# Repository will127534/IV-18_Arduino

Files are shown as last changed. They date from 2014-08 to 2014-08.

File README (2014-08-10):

This program is to control MAX6921 for IV-18 VFD display 
To control the MAX6921 needs three pin,CLK,LOAD DATA,just like the shift regester
But the difference is MAX6921 is just using 19bit with LSB first.

Another thing is how you connect MAX6921 to the IV-18 tube.
the connection begin from the third one,with a,b,c,e,d,f,g,h,i
then comes with 1~9 digit.
the digit is already inverted(since LSB first)

The program also pack the DS1307 control (http://bildr.org/2011/03/ds1307-arduino/) to provide RTC .  

To enter the current time,just using the COM port and enter S, and you can enter the current time.

Here is the BLOG:(chinese)
http://will-123456.blogspot.tw/2014/01/iv-18-arduino-shield.html

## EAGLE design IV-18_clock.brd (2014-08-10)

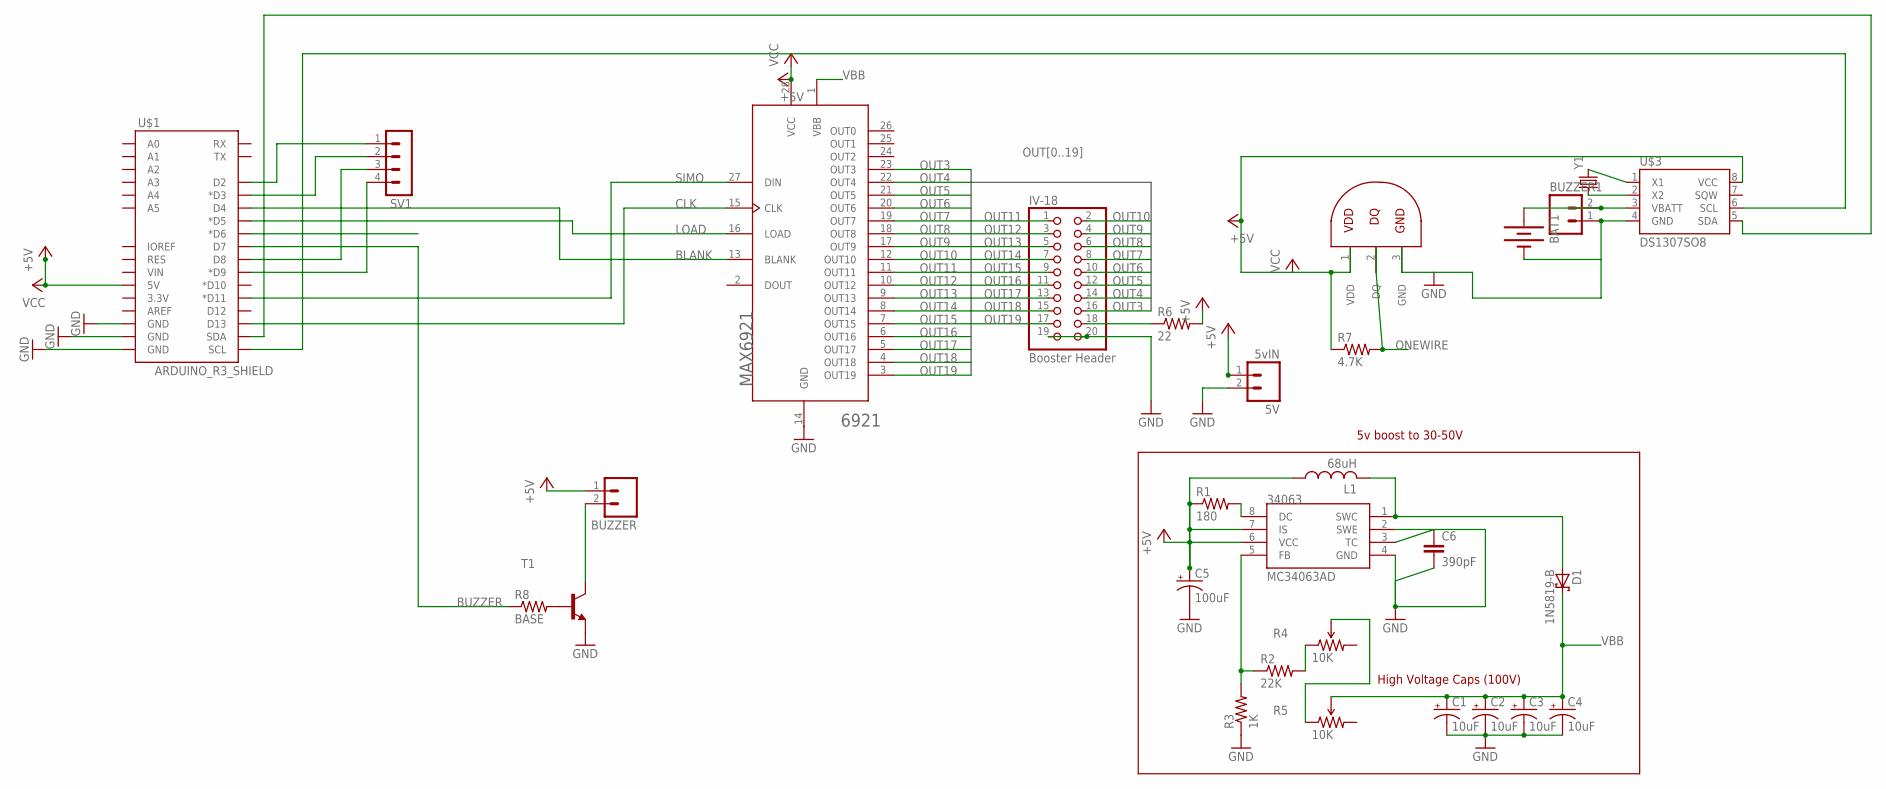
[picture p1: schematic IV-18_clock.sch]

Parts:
5V: 5vIN; 1X02
6921: MAX6921_AFSOIC(W); SO28L
34063: MC34063AD; SOIC8
BAT1: BATTERY20PTH; BATTCOM_20MM_PTH
BUZZER, BUZZER1: 1X02
C1, C2, C3, C4: 10uF; E2,5-6
C5: 100uF; E2,5-6
C6: 390pF; CAP-PTH-5MM
D1: 1N5819-B; DO41-7.6
DS18B20: DS18B20; TO92-CBE@1
IV-18: Booster Header; 2X10
L1: 68uH; 6000-XXXX-RC
R1: 180; 0204/7
R2: 22K; 0204/7
R3: 1K; 0204/7
R4, R5: 10K; TRIM_POT_PTH
R6: 22; 0204/7
R7: 4.7K; 0204/7
R8: BASE; 0204/7
SV1: MA04-1
T1: TO92-EBC
U$1: ARDUINO_R3_SHIELD; UNO_R3_SHIELD
U$3: DS1307SO8; SO08
Y1: CRYSTALTC26H_EZ; TC26HEZ

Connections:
+5V: 5V.1, 6921.28 (VCC), 34063.6 (VCC), 34063.7 (IS), BUZZER.1, C5.+, DS18B20.1 (VDD), L1.1, R1.1, R6.2, R7.1, U$1.5V, U$3.8 (VCC)
BLANK: 6921.13 (BLANK), U$1.D4
BUZZER: R8.1, U$1.D7
CLK: 6921.15 (CLK), U$1.D13
GND: 5V.2, 6921.14 (GND), 34063.2 (SWE), 34063.4 (GND), BAT1.2 (-), BUZZER1.1, C1.-, C2.-, C3.-, C4.-, C5.-, C6.2, DS18B20.3 (GND), IV-18.19, IV-18.20, R3.1, T1.E, U$1.GND@0 (GND), U$1.GND@1 (GND), U$1.GND@2 (GND), U$3.4 (GND)
LOAD: 6921.16 (LOAD), U$1.D5 (*D5)
unnamed: IV-18.18, R6.1
unnamed: R2.2, R4.1 (CCW)
unnamed: 34063.1 (SWC), D1.A, L1.2
unnamed: R4.2 (WIPER), R5.1 (CCW)
unnamed: 34063.8 (DC), R1.2
unnamed: 34063.3 (TC), C6.1
unnamed: 34063.5 (FB), R2.1, R3.2
unnamed: R8.2, T1.B
unnamed: SV1.1, U$1.D2
unnamed: SV1.2, U$1.D3 (*D3)
unnamed: SV1.3, U$1.D8
unnamed: BUZZER.2, T1.C
unnamed: U$3.1 (X1), Y1.2
unnamed: U$3.2 (X2), Y1.1
unnamed: U$1.SCL, U$3.6 (SCL)
unnamed: BAT1.1 (+), BUZZER1.2, U$3.3 (VBATT)
unnamed: U$1.SDA, U$3.5 (SDA)
unnamed: SV1.4, U$1.D9 (*D9)
ONEWIRE: DS18B20.2 (DQ), R7.2, U$1.D6 (*D6)
OUT3: 6921.23 (OUT3), IV-18.16
OUT4: 6921.22 (OUT4), IV-18.14
OUT5: 6921.21 (OUT5), IV-18.12
OUT6: 6921.20 (OUT6), IV-18.10
OUT7: 6921.19 (OUT7), IV-18.8
OUT8: 6921.18 (OUT8), IV-18.6
OUT9: 6921.17 (OUT9), IV-18.4
OUT10: 6921.12 (OUT10), IV-18.2
OUT11: 6921.11 (OUT11), IV-18.1
OUT12: 6921.10 (OUT12), IV-18.3
OUT13: 6921.9 (OUT13), IV-18.5
OUT14: 6921.8 (OUT14), IV-18.7
OUT15: 6921.7 (OUT15), IV-18.9
OUT16: 6921.6 (OUT16), IV-18.11
OUT17: 6921.5 (OUT17), IV-18.13
OUT18: 6921.4 (OUT18), IV-18.15
OUT19: 6921.3 (OUT19), IV-18.17
SIMO: 6921.27 (DIN), U$1.D11 (*D11)
VBB: 6921.1 (VBB), C1.+, C2.+, C3.+, C4.+, D1.C, R5.2 (WIPER)

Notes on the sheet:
5v boost to 30-50V
High Voltage Caps (100V)

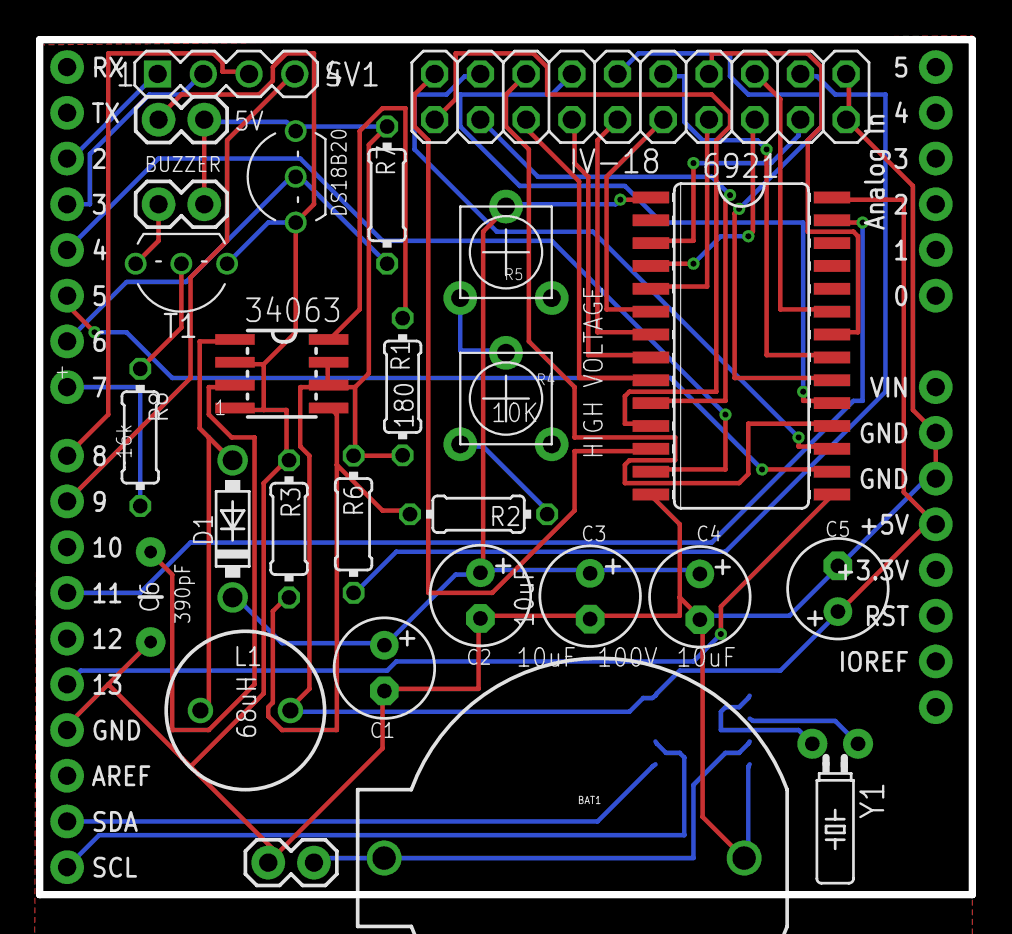
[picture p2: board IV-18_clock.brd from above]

Board: 2 copper layers, 51.8 x 47.5 mm, 29 parts (1 on the bottom side), 44 nets.

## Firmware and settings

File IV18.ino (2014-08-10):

#include <Arduino.h>

#include <Wire.h>  
#include <Time.h>  
#define DS1307_ADDRESS 0x68
#define  dataPin  11
#define  clockPin 13
#define  loadPin  5

byte zero = 0x00;
const byte segFont[] ={B00111111, B00000110, B01011011, B01001111,B01100110, B01101101, B01111100, B00000111,B01111111, B01100111, B01000000, B00000000};

int lastsecond = 0;

byte bChars[10] ;
int dChars[10] ;

byte seconds;
byte hours;
byte minutes;
int weekDay ; //0-6 -> sunday - Saturday
  int monthDay ;
  int months ;
  int years ;


void setup()
{
  pinMode(loadPin, OUTPUT);
  pinMode(clockPin, OUTPUT);
  pinMode(dataPin, OUTPUT);
  pinMode(A1, OUTPUT);
  digitalWrite(A1,HIGH);
  Serial.begin(9600);
  Wire.begin();
  timetoIV18(12,75,34);
  printDate();
  RefreshIV18();

}
int flag =0;
void loop(){
if(analogRead(A0)>55){
    flag =1;
}
while (flag){
  delay(100);
  if(analogRead(A0)<30){
        flag =0;
  }

}

  printDate();
//  datetoIV18(years,months,monthDay);
//for(int j=0;j<=1000;j++){
//RefreshIV18();
//}
 // printDate();
     timetoIV18(hours,minutes,seconds);
  //  for(int j=0;j<=1000;j++){
     RefreshIV18();
    // }


}
void serialEvent(){
int answer = Serial.read();
if (answer=='S'){
  Serial.read();
  setTime();
}
}

void setTime() {
  Serial.read();
  Serial.println("Please enter the current year, 00-99. - ");

  byte yearsett = readByteq();
  Serial.println("Please enter the current month, 1-12. - ");
  byte monthset = readByteq();
  //Serial.println(months[monthset-1]);
  Serial.println("Please enter the current day of the month, 1-31. - ");
  byte monthdayset = readByteq();
  //Serial.println(monthday);
  Serial.println("Please enter the current day of the week, 1-7.");
  Serial.println("1 Sun | 2 Mon | 3 Tues | 4 Weds | 5 Thu | 6 Fri | 7 Sat - ");
  byte weekdayset = readByteq();
  //Serial.println(days[weekday-1]);
  Serial.println("Please enter the current hour in 24hr format, 0-23. - ");
  byte hourset = readByteq();
  //Serial.println(hour);
  Serial.println("Please enter the current minute, 0-59. - ");
  byte minuteset = readByteq();
  //Serial.println(minute);
  Serial.println("Please enter the current second, 0-59. - ");
  byte secondset = readByteq();
  Serial.println("The data has been entered.");

  // The following codes transmits the data to the RTC
  Wire.beginTransmission(0x68);
  Wire.write(byte(0));
  Wire.write(decToBcd(secondset));
  Wire.write(decToBcd(minuteset));
  Wire.write(decToBcd(hourset));
  Wire.write(decToBcd(weekdayset));
  Wire.write(decToBcd(monthdayset));
  Wire.write(decToBcd(monthset));
  Wire.write(decToBcd(yearsett));
  Wire.write(byte(0));
  Wire.endTransmission();
  // Ends transmission of data
}


byte readByteq() {
  while (!Serial.available()) delay(10);
  byte reading = 0;
  byte incomingByte = Serial.read();
  while (incomingByte != '\n') {
    if (incomingByte >= '0' && incomingByte <= '9')
      reading = reading * 10 + (incomingByte - '0');
    else;
    incomingByte = Serial.read();
  }
  Serial.flush();
  return reading;
}
void RefreshIV18() 
{ 
  for (int count = 1;count<=9;count++){

    long data=0;
    data = segFont[bChars[count]];
    bitSet(data,17-count);
    if (dChars[count] == 1){
      bitSet(data,7);
    }
    digitalWrite(loadPin, LOW); 
  //Shiftin 20 bits
  for(byte i=0; i<20; i++) 
  { 
    //clockPin LOW
    digitalWrite(clockPin, LOW);
    //datapin bit to 1 OR 0 
    digitalWrite(dataPin,bitRead(data, i));
    //Set clockPin HIGH
    digitalWrite(clockPin, HIGH); 
  }

  digitalWrite(loadPin, HIGH);

}
}

byte bcdToDec(byte val)  {
// Convert binary coded decimal to normal decimal numbers
return ( (val/16*10) + (val%16) );
}


void timetoIV18(byte h,byte m,byte s)
{
  memset(bChars,0,sizeof(dChars));
  memset(dChars,0,sizeof(bChars));
  bChars[7]=h % 10; 
  bChars[8]=h / 10;
  bChars[6]=11;
  dChars[6]=1;

  bChars[4]=m % 10; 
  bChars[5]=m / 10;
 bChars[3]=11;
  dChars[3]=1;

  bChars[1]=s % 10; 
  bChars[2]=s / 10;

  

}
void datetoIV18(int yy,int mm,int dd)
{
  memset(dChars,0,sizeof(dChars));
  memset(bChars,0,sizeof(bChars));
 
  bChars[8]=yy/10;
  bChars[7]=yy%10; 
  
  bChars[6]=10;

  bChars[5]=mm/10; 
  bChars[4]=mm%10;

  bChars[3]=10;

  bChars[2]=dd / 10;
  bChars[1]=dd % 10; 

}


byte decToBcd(byte val){
// Convert normal decimal numbers to binary coded decimal
return ( (val/10*16) + (val%10) );
}

void printDate(){
  Wire.beginTransmission(DS1307_ADDRESS);
  Wire.write(zero);
  Wire.endTransmission();

  Wire.requestFrom(DS1307_ADDRESS, 7);

  seconds = bcdToDec(Wire.read());
  minutes = bcdToDec(Wire.read());
  hours = bcdToDec(Wire.read() & 0b111111); //24 hour time
  
   weekDay = bcdToDec(Wire.read()); //0-6 -> sunday - Saturday
  monthDay = bcdToDec(Wire.read());
  months = bcdToDec(Wire.read());
   years = bcdToDec(Wire.read());
/*
  //print the date EG   3/1/11 23:59:59
  Serial.print(months);
  Serial.print("/");
  Serial.print(monthDay);
  Serial.print("/");
  Serial.print(years);
  Serial.print(" ");
  Serial.print(hours);
  Serial.print(":");
  Serial.print(minutes);
  Serial.print(":");
  Serial.println(seconds);
  */
}

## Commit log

2014-02-01 Ver 1.0
    First working program on the IV-18 Arduino Shield
2014-08-10 Ver 1.1
    adding a switch to turn off the display
    also adding PCB file
    [TubeClockBooster1.2.brd, TubeClockBooster1.2.sch]
2014-08-10 Ver 1.1
    [IV-18_clock.brd, IV-18_clock.sch]

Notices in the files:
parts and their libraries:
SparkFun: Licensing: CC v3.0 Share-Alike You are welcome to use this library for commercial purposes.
